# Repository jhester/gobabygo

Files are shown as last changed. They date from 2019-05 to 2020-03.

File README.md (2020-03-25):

GoBabyGo Project Repository
=====

This repo holds the firmware, software, hardware, and other files fort the GoBabyGo utilization project.

#### Visualize Data with Google Earth

Use the `create_nmea.py` script in the `analysis` folder to convert gathered GPS data into a single [NMEA file](https://www.gpsworld.com/what-exactly-is-gps-nmea-data/) which can be dragged into [Google Earth Pro (free)](https://www.google.com/earth/versions/#earth-pro), the desktop app.

To do this you need Python, once installed run the following in a command prompt or in a terminal where you specify the path to all the data and then specify the name of the NMEA file:

```
python create_nmea.py folder/where/files/are -o outputfile.nmea
```

If you import only tracks, it renders faster  but you dont get each value. If you import the LineStrings then it shows every value and also shows direction and time which is nice.

This could be trimmed down to show per day possibly.

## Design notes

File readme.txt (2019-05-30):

How to use it?

1. install SW4STM32
2. open SW4STM32/STM32L47xx_SensorTile/.project

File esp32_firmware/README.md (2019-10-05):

ESP32 Thing Based GoBabyGo! Firmware
=====

After difficulty deploying and programming SensorTiles we opted to go with the higher power but more feature rich ESP32.

Specifically this breakout board [SparkFun ESP32 Thing](https://www.sparkfun.com/products/13907). Which has a chip that allows BLE and Wifi connections along with decent performance and ease of programming using Arduino. 

We deploy with the [SparkFun ESP32 Thing Motion Shield](https://www.sparkfun.com/products/14430) connected to a [GPS Receiver - GP-20U7 (56 Channel)](https://www.sparkfun.com/products/13740).

Thie allows us to get GPS coordinates, very accurate global time, and IMU data for tracking movement. This is all stored to the USB. GPS updates once per second. IMU updates 10 times a second. Tested and can get a GPS lock indoors and when moved around it can map the movement. 

#### Function
1. Blue led pulses while trying to find a lock, and is solid blue when lock found.
2. The sd card can be taken out without corrupting data, but if inserted again, need to click the reset button and it will pick up from where it left off.
3. files only grow to a set size, then a new file is created for data, in the format of IMU_00001.txt, GPS_00001.txt, IMU_00002.txt and so on
4. the files are synchronized by a local timer which is the first column in each file, so all data can be aligned.
5. the GPS gives exact time (basically the standard time that everything else is set by). So even if a power failure happens we can always get the right time just by asking GPS.

#### Resources
1. [NMEA reference for GPS data](https://www.sparkfun.com/datasheets/GPS/NMEA%20Reference%20Manual-Rev2.1-Dec07.pdf)
2. [Motion breakout guide.](https://learn.sparkfun.com/tutorials/esp32-thing-motion-shield-hookup-guide)

#### TODO and Ideas

**Data Upload:** Use the BLE and Wifi together to create an in-wild auto data upload mechanism. The process would be:
1. Read network.txt SD card for Wifi info and attempt to authenticate with it if it exists.
2. If this file does not exist, OR the network is unavailable. Then go into BLE mode and listen for a connection. Also go about normal data collection.
3. If a connection is made in BLE mode, talk over UART and ask for Wifi SSID and password. Then connect and store it once found.

**Even easier. Have the participants or study coordinator make a file on the SD card with the SSID and password for the network and then the ESP32 will just connect to it.**

esp 32 imag

---------

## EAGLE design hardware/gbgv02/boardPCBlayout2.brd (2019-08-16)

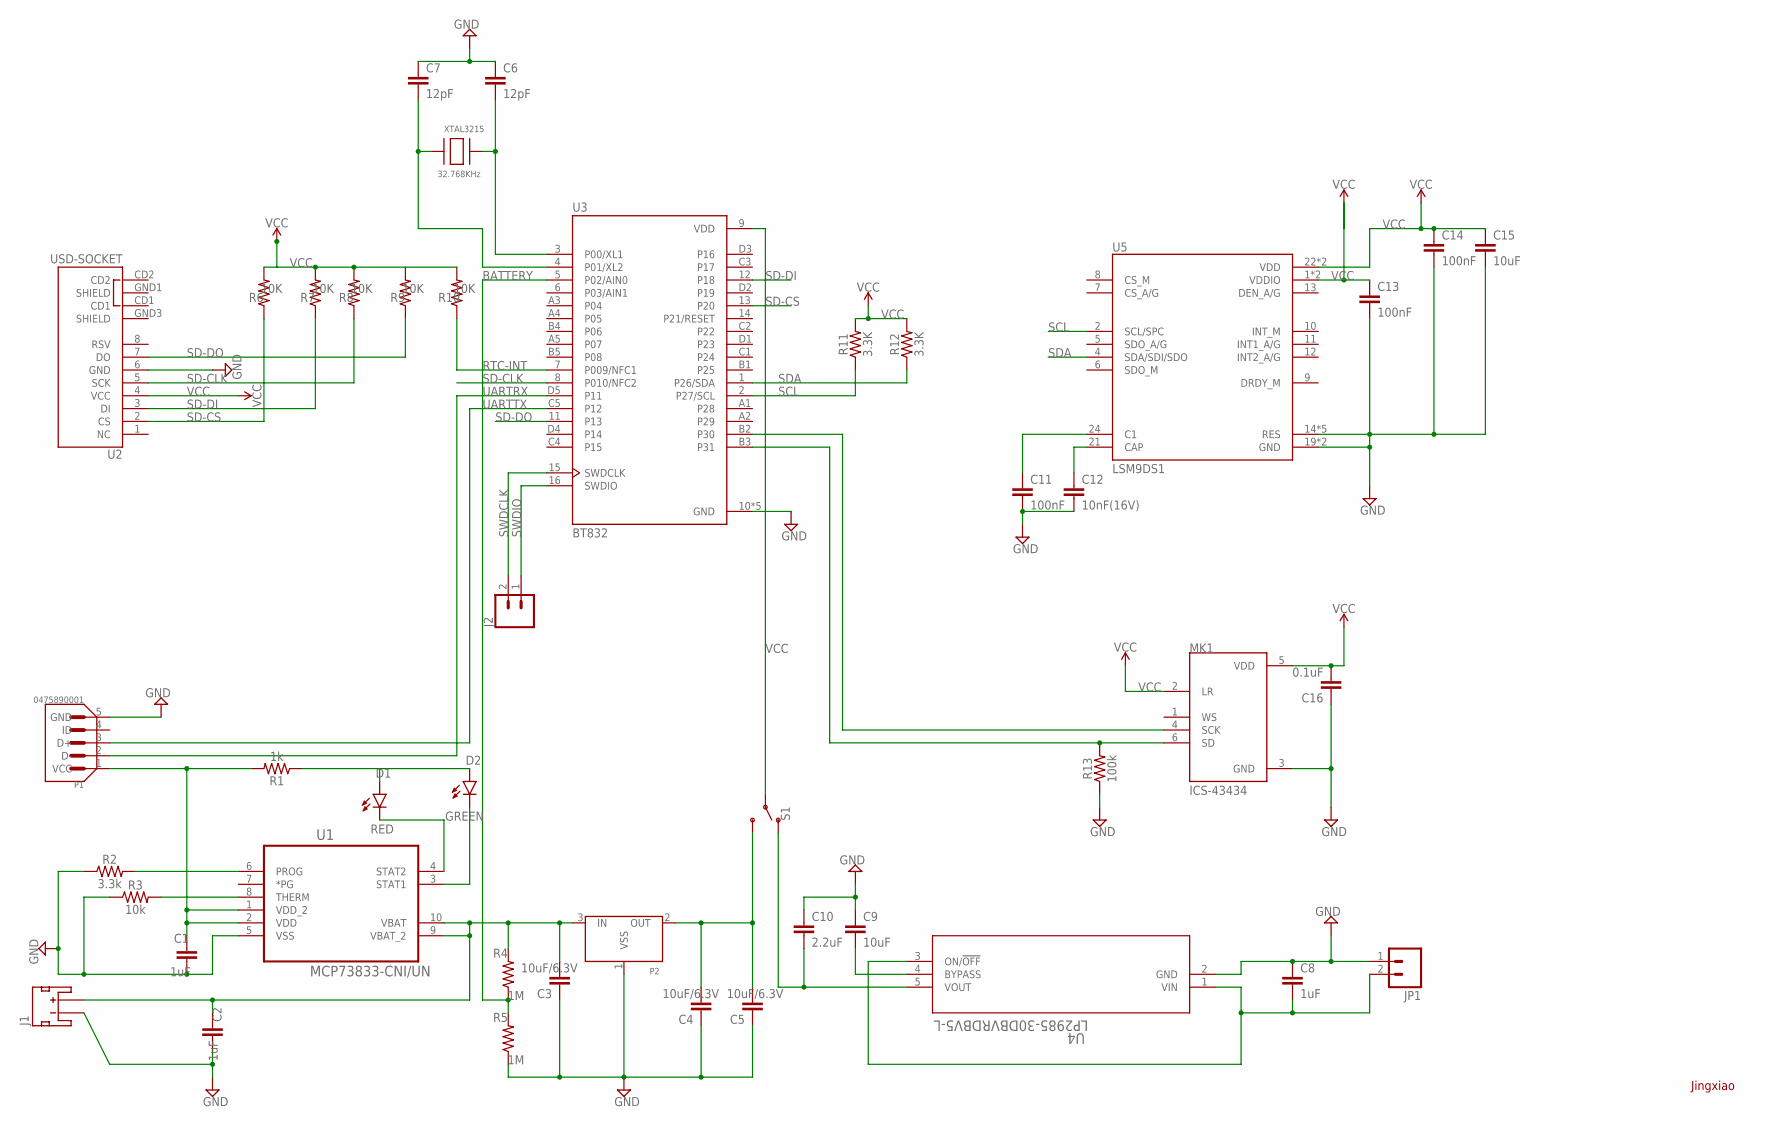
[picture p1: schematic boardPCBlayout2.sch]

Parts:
C1, C2: 1uF; CAP_0603
C3, C4, C5: 10uF/6.3V; 0603
C6, C7: 12pF; 0603
C8: 1uF; 0603
C9, C15: 10uF; 0603
C10: 2.2uF; 0603
C11, C13, C14: 100nF; 0603
C12: 10nF(16V); 0603
C16: 0.1uF; 0603
D1: RED; LED-0603
D2: GREEN; LED-0603
J1: JST_2MM_MALE; JST-2-SMD
J2: CONN_02; 1X02
JP1: M023.5MM-NO_SILK; SCREWTERMINAL-3.5MM-2-NS
MK1: ICS-43434; MIC_ICS-43434
P1: 0475890001; MOLEX_0475890001
P2: XC6206SOT-23; XC6206_SOT-23
R1: 1k; 0603
R2: 3.3k; 0603
R3: 10k; 0603
R4, R5: 1M; 0603
R6, R7, R8, R9, R10: 10K; 0603
R11, R12: 3.3K; 0603
R13: 100k; 0603
S1: SWITCH-SPDT-PTH-11.6X4.0MM; SWITCH_SPDT_PTH_11.6X4.0MM
U1: MCP73833-CNI/UN; SOP50P490X110-10N
U2: USD-SOCKET; MICROSD_1:1
U3: BT832; BLEMODULE_BT832
U4: LP2985-30DBVRDBV5-L; DBV5-L
U5: LSM9DS1; PQFN24P43_350X300X102L35X23N
XTAL3215: 32.768KHz; XTAL3215

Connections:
BATTERY: R4.1, R5.2, U3.5 (P02/AIN0)
GND: C1.2, C3.1, C4.1, C5.1, C6.1, C7.1, C8.1, C9.1, C10.1, C11.2, C12.2, C13.2, C14.2, C15.2, C16.1, JP1.1, MK1.3 (GND), P1.5 (GND), P2.1 (VSS), R2.1, R3.1, R5.1, R13.1, U1.5 (VSS), U2.6 (GND), U3.10 (GND), U3.A0 (GND), U3.B0 (GND), U3.C0 (GND), U3.D0 (GND), U4.2 (GND), U5.14 (RES), U5.15 (RES), U5.16 (RES), U5.17 (RES), U5.18 (RES), U5.19 (GND), U5.20 (GND)
unnamed: C1.1, P1.1 (VCC), R1.2, U1.1 (VDD_2), U1.2 (VDD)
unnamed: D1.C, U1.4 (STAT2)
unnamed: D1.A, D2.A, R1.1
unnamed: D2.C, U1.3 (STAT1)
unnamed: C2.2, J1.1 (-)
unnamed: C2.1, C3.2, J1.2 (+), P2.3 (IN), R4.2, U1.9 (VBAT_2), U1.10 (VBAT)
unnamed: R2.2, U1.6 (PROG)
unnamed: R3.2, U1.8 (THERM)
unnamed: MK1.6 (SD), R13.2, U3.B3 (P31)
unnamed: C7.2, U3.4 (P01/XL2), XTAL3215.P$1
unnamed: C6.2, U3.3 (P00/XL1), XTAL3215.P$2
unnamed: C10.2, S1.1 (O), U4.5 (VOUT)
unnamed: C12.1, U5.21 (CAP)
unnamed: C8.2, JP1.2, U4.1 (VIN), U4.3 (ON/!OFF)
unnamed: C9.2, U4.4 (BYPASS)
unnamed: C11.1, U5.24 (C1)
unnamed: C4.2, C5.2, P2.2 (OUT), S1.3 (S)
unnamed: MK1.4 (SCK), U3.B2 (P30)
RTC-INT: R10.1, U3.7 (P009/NFC1)
SCL: R11.1, U3.2 (P27/SCL), U5.2 (SCL/SPC)
SD-CLK: R8.1, U2.5 (SCK), U3.8 (P010/NFC2)
SD-CS: R6.1, U2.2 (CS), U3.13 (P20)
SD-DI: R7.1, U2.3 (DI), U3.12 (P18)
SD-DO: R9.1, U2.7 (DO), U3.11 (P13)
SDA: R12.1, U3.1 (P26/SDA), U5.4 (SDA/SDI/SDO)
SWDCLK: J2.2, U3.15 (SWDCLK)
SWDIO: J2.1, U3.16 (SWDIO)
UARTRX: P1.2 (D-), U3.D5 (P11)
UARTTX: P1.3 (D+), U3.C5 (P12)
VCC: C13.1, C14.1, C15.1, C16.2, MK1.2 (LR), MK1.5 (VDD), R6.2, R7.2, R8.2, R9.2, R10.2, R11.2, R12.2, S1.2, U2.4 (VCC), U3.9 (VDD), U5.1 (VDDIO), U5.3 (VDDIO), U5.22 (VDD), U5.23 (VDD)

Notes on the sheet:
Jingxiao

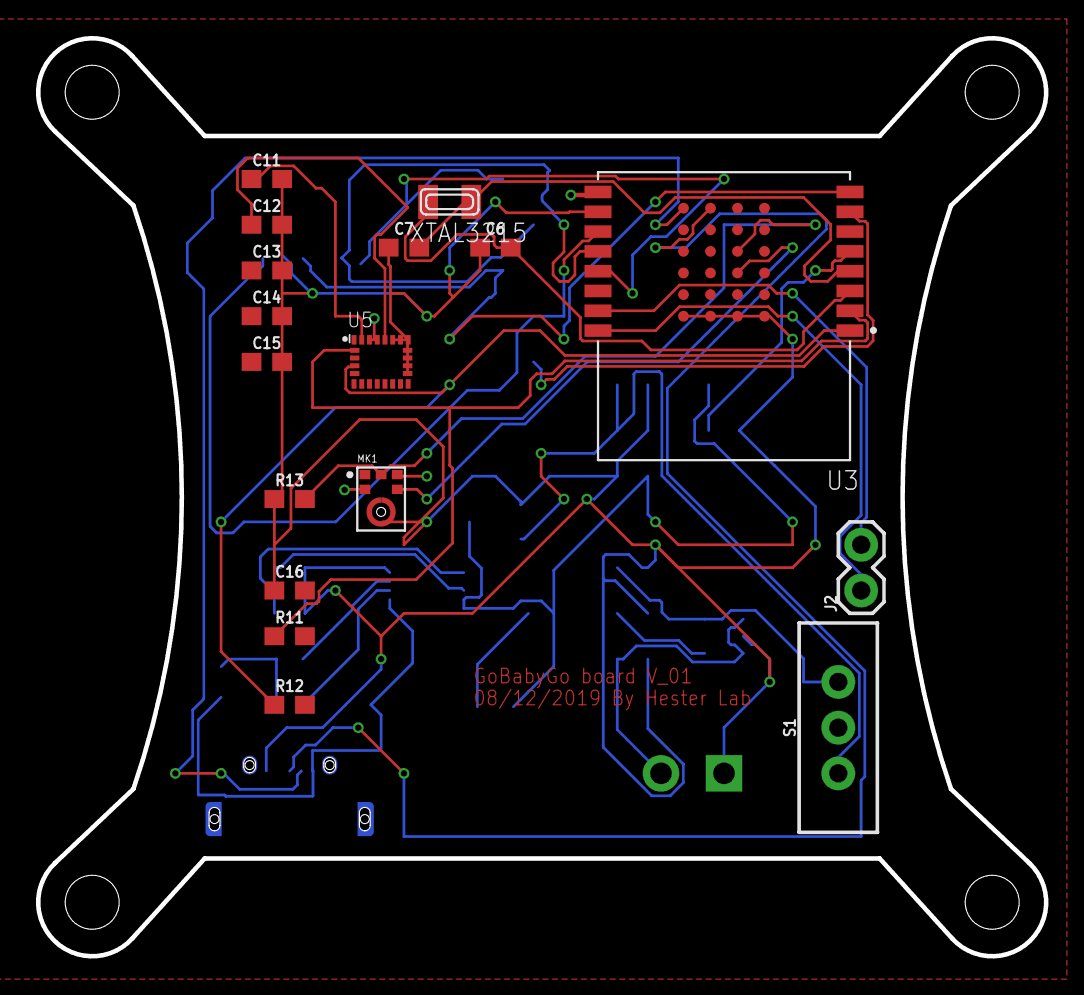
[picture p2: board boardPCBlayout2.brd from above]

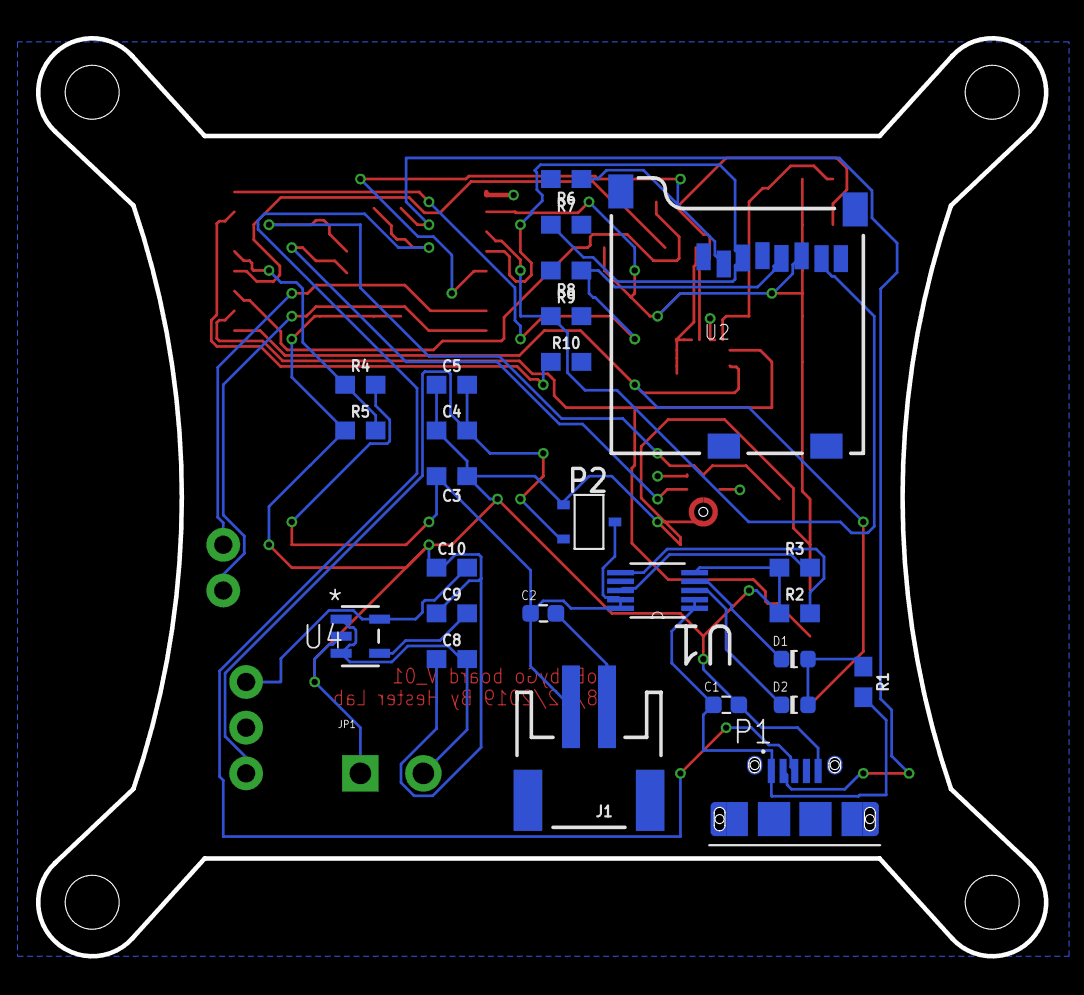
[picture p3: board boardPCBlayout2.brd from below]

Board: 2 copper layers, 56.0 x 51.0 mm, 44 parts (27 on the bottom side), 32 nets.

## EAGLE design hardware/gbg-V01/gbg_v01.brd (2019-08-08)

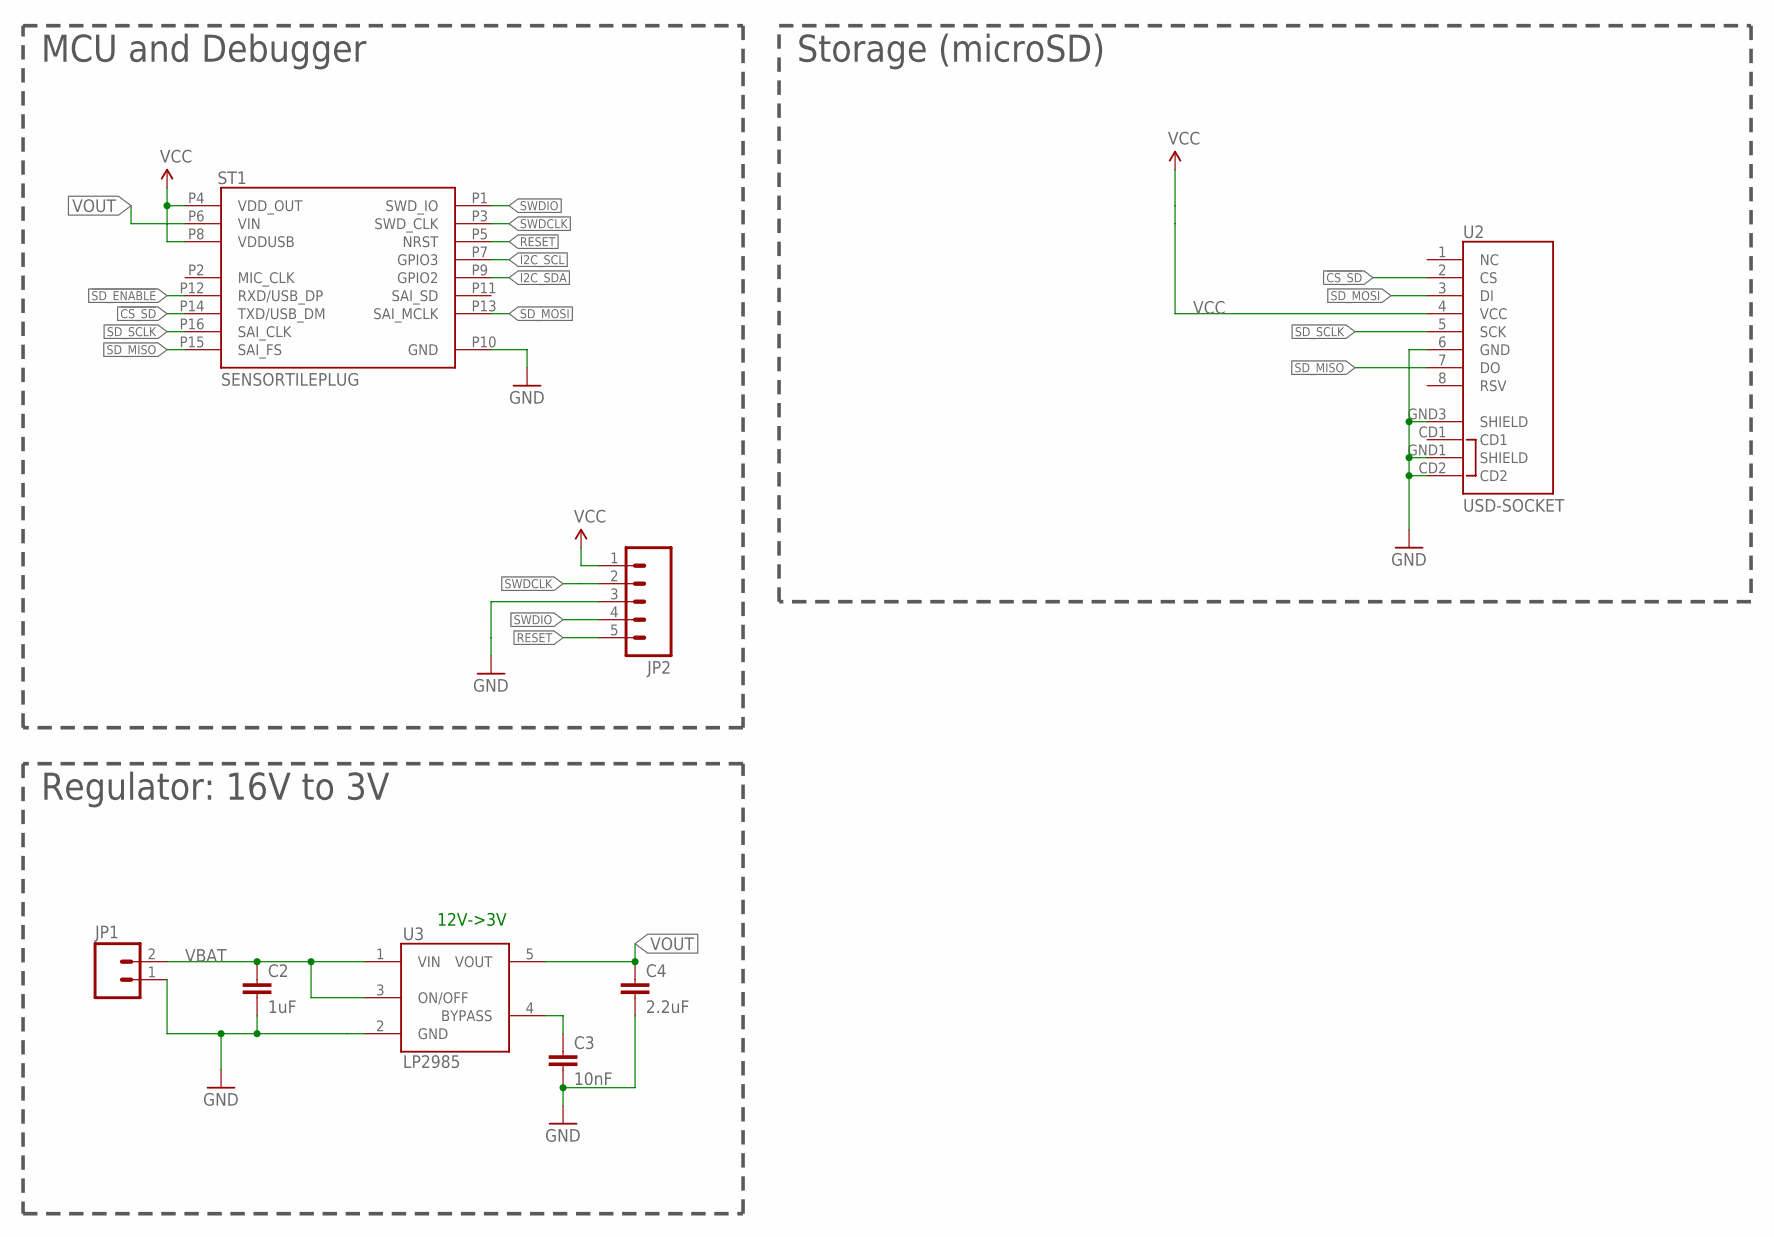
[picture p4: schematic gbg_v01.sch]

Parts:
C2: 1uF; 0603
C3: 10nF; 0603
C4: 2.2uF; 0603
JP1: M025MM; SCREWTERMINAL-5MM-2
JP2: M05LOCK; 1X05_LOCK
ST1: SENSORTILEPLUG; BM10JC16
U2: USD-SOCKET; MICROSD_1:1; DIGIKEY WM3290CT-ND
U3: LP2985AIM5-3.3; SOT25; MPN LP2985-30DBVR; DIGIKEY 296-32152-1-ND

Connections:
!CS_SD: ST1.P14 (TXD/USB_DM), U2.2 (CS)
!SD_ENABLE: ST1.P12 (RXD/USB_DP)
BYPASS: C3.1, U3.4 (BYPASS)
GND: C2.2, C3.2, C4.2, JP1.1, JP2.3, ST1.P10 (GND), U2.6 (GND), U2.CD2, U2.GND1 (SHIELD), U2.GND3 (SHIELD), U3.2 (GND)
I2C_SCL: ST1.P7 (GPIO3)
I2C_SDA: ST1.P9 (GPIO2)
RESET: JP2.5, ST1.P5 (NRST)
SD_MISO: ST1.P15 (SAI_FS), U2.7 (DO)
SD_MOSI: ST1.P13 (SAI_MCLK), U2.3 (DI)
SD_SCLK: ST1.P16 (SAI_CLK), U2.5 (SCK)
SWDCLK: JP2.2, ST1.P3 (SWD_CLK)
SWDIO: JP2.4, ST1.P1 (SWD_IO)
VBAT: C2.1, JP1.2, U3.1 (VIN), U3.3 (ON/OFF)
VCC: JP2.1, ST1.P4 (VDD_OUT), ST1.P8 (VDDUSB), U2.4 (VCC)
VOUT: C4.1, ST1.P6 (VIN), U3.5 (VOUT)

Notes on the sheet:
Storage (microSD)
12V->3V
MCU and Debugger
Regulator: 16V to 3V

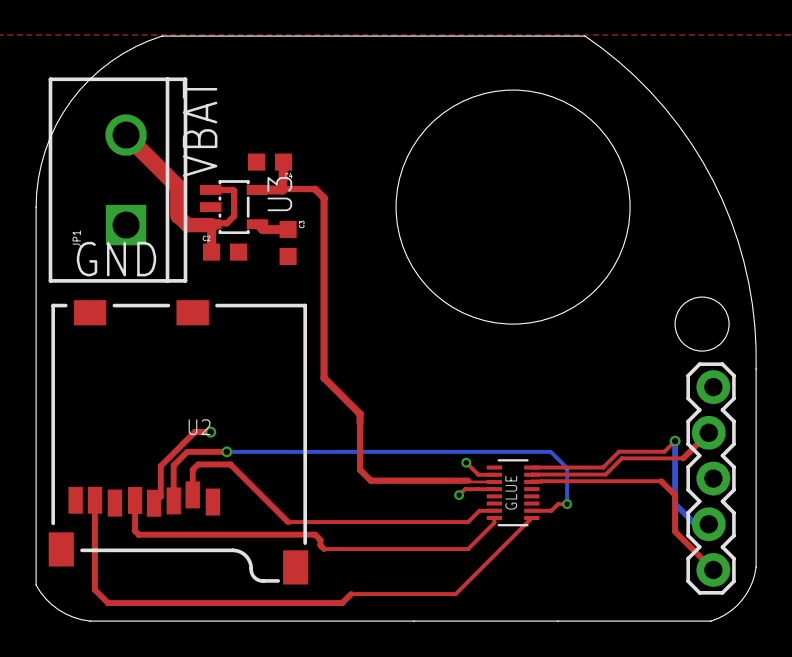
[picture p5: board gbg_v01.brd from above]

Board: 2 copper layers, 40.0 x 32.5 mm, 8 parts (0 on the bottom side), 12 nets.

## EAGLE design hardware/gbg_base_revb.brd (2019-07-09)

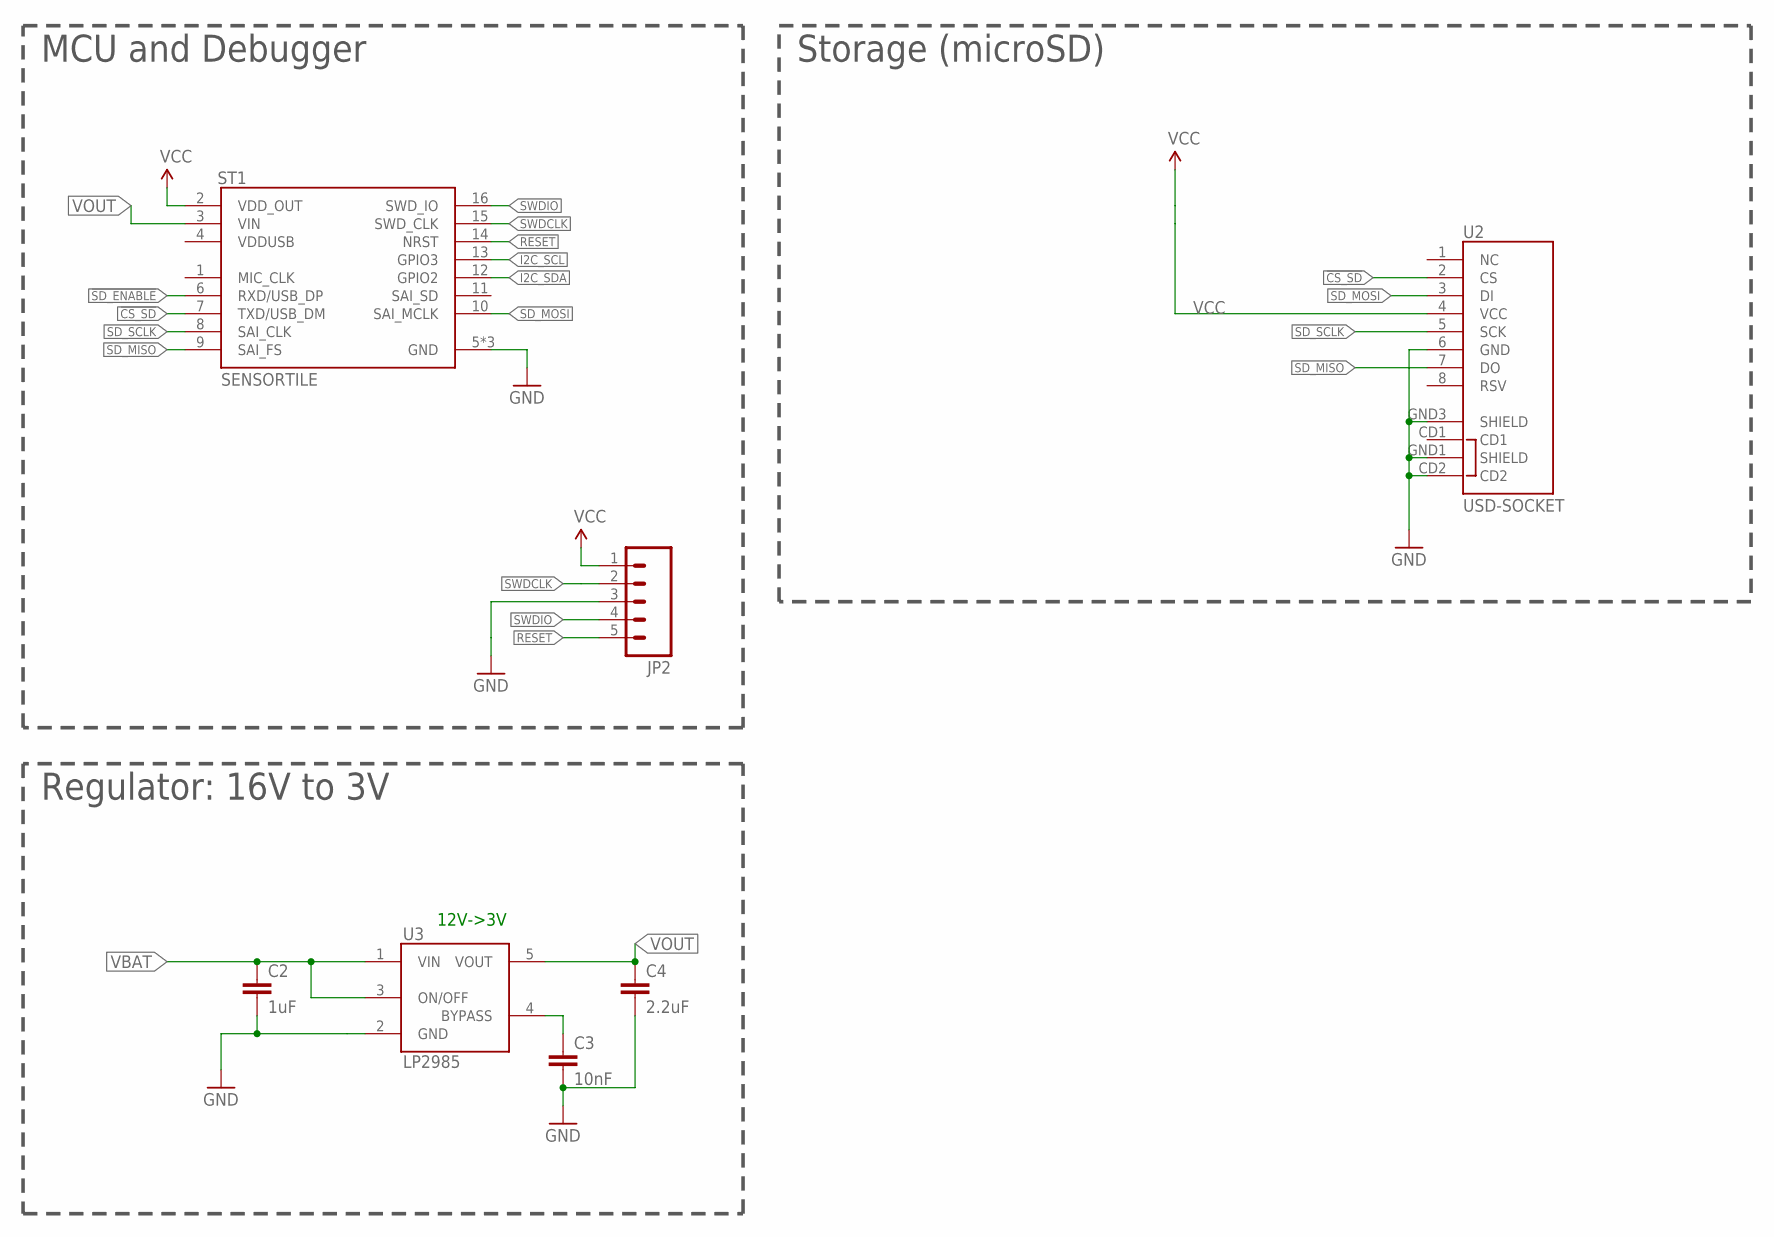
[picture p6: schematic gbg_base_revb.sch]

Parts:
C2: 1uF; 0603
C3: 10nF; 0603
C4: 2.2uF; 0603
JP2: M05LOCK; 1X05_LOCK
ST1: SENSORTILE
U2: USD-SOCKET; MICROSD_1:1; DIGIKEY WM3290CT-ND
U3: LP2985AIM5-3.3; SOT25; MPN LP2985-30DBVR; DIGIKEY 296-32152-1-ND

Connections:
!CS_SD: ST1.7 (TXD/USB_DM), U2.2 (CS)
!SD_ENABLE: ST1.6 (RXD/USB_DP)
BYPASS: C3.1, U3.4 (BYPASS)
GND: C2.2, C3.2, C4.2, JP2.3, ST1.5 (GND), ST1.17 (GND), ST1.18 (GND), U2.6 (GND), U2.CD2, U2.GND1 (SHIELD), U2.GND3 (SHIELD), U3.2 (GND)
I2C_SCL: ST1.13 (GPIO3)
I2C_SDA: ST1.12 (GPIO2)
RESET: JP2.5, ST1.14 (NRST)
SD_MISO: ST1.9 (SAI_FS), U2.7 (DO)
SD_MOSI: ST1.10 (SAI_MCLK), U2.3 (DI)
SD_SCLK: ST1.8 (SAI_CLK), U2.5 (SCK)
SWDCLK: JP2.2, ST1.15 (SWD_CLK)
SWDIO: JP2.4, ST1.16 (SWD_IO)
VBAT: C2.1, U3.1 (VIN), U3.3 (ON/OFF)
VCC: JP2.1, ST1.2 (VDD_OUT), U2.4 (VCC)
VOUT: C4.1, ST1.3 (VIN), U3.5 (VOUT)

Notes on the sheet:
Storage (microSD)
12V->3V
MCU and Debugger
Regulator: 16V to 3V

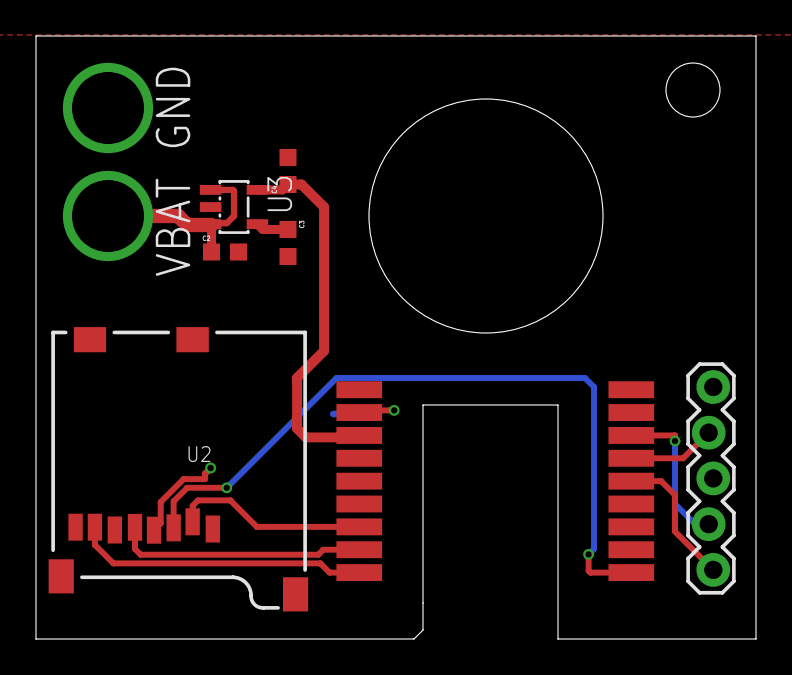
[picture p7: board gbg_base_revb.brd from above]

Board: 2 copper layers, 40.0 x 33.5 mm, 7 parts (0 on the bottom side), 12 nets.

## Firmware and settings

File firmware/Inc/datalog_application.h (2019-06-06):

/**
  ******************************************************************************
  * @file    datalog_application.h
  * @author  SRA - Central Labs
  * @version V2.0.0
  * @date    5-Feb-2019
  * @brief   Header for datalog_application.c module.
  ******************************************************************************
  * @attention
  *
  * <h2><center>&copy; COPYRIGHT(c) 2014 STMicroelectronics</center></h2>
  *
  * Licensed under MCD-ST Liberty SW License Agreement V2, (the "License");
  * You may not use this file except in compliance with the License.
  * You may obtain a copy of the License at:
  *
  *        http://www.st.com/software_license_agreement_liberty_v2
  *
  * Unless required by applicable law or agreed to in writing, software
  * distributed under the License is distributed on an "AS IS" BASIS,
  * WITHOUT WARRANTIES OR CONDITIONS OF ANY KIND, either express or implied.
  * See the License for the specific language governing permissions and
  * limitations under the License.
  *
  ******************************************************************************
  */

/* Define to prevent recursive inclusion -------------------------------------*/
#ifndef __DATALOG_APPLICATION_H
#define __DATALOG_APPLICATION_H

#ifdef __cplusplus
extern "C" {
#endif

#include "cube_hal.h"
#include "lsm6dsm_settings.h"
#include "lsm303agr_settings.h"
#include "SensorTile_env_sensors.h"
#include "hts221_settings.h"
#include "lps22hb_settings.h"
#include "SensorTile_motion_sensors.h"
#include "SensorTile_motion_sensors_ex.h"
  
#define SAMPLING_10Hz
//#define SAMPLING_50Hz
//#define SAMPLING_100Hz 

#if defined( SAMPLING_10Hz)
  #define DEFAULT_uhCCR1_Val 190
  #define ACCELERO_ODR 83.3f     /* after filtering will be 46.2 Hz */
  #define ACCELERO_DIV LSM6DSM_ACC_GYRO_HPCF_XL_DIV9
  #define GYRO_ODR 10.4f
  #define MAGNETO_ODR 10.0f
  #define PRESSURE_ODR 10.0f
  #define DATA_PERIOD_MS     (100)

#elif defined( SAMPLING_50Hz)
  #define DEFAULT_uhCCR1_Val 190
  #define ACCELERO_ODR 416.0f     /* after filtering will be 46.2 Hz */
  #define ACCELERO_DIV LSM6DSM_ACC_GYRO_HPCF_XL_DIV9
  #define GYRO_ODR 52.0f
  #define MAGNETO_ODR 50.0f
  #define PRESSURE_ODR 50.0f
  #define DATA_PERIOD_MS     (20)

#elif defined( SAMPLING_100Hz)
  #define DEFAULT_uhCCR1_Val 100
  #define ACCELERO_ODR  833.0f    /* after filtering will be 93 Hz */
  #define ACCELERO_DIV LSM6DSM_ACC_GYRO_HPCF_XL_DIV9
  #define GYRO_ODR 104.0f
  #define MAGNETO_ODR 100.0f
  #define PRESSURE_ODR 50.0f
  #define DATA_PERIOD_MS     (10)
#endif

#define TEMPERATURE_ODR 12.5f
#define HUMIDITY_ODR 12.5f

typedef enum
{
  USB_Datalog = 0,
  SDCARD_Datalog
} LogInterface_TypeDef;


typedef struct
{
  uint32_t ms_counter;
  float pressure;
  float humidity;
  float temperature;
  BSP_MOTION_SENSOR_Axes_t acc;
  BSP_MOTION_SENSOR_Axes_t gyro;
  BSP_MOTION_SENSOR_Axes_t mag;
} T_SensorsData;
  
extern LogInterface_TypeDef LoggingInterface;
extern volatile uint8_t SD_Log_Enabled;

void floatToInt( float in, int32_t *out_int, int32_t *out_dec, int32_t dec_prec );

void DATALOG_SD_Init(void);
uint8_t DATALOG_SD_Log_Enable(void);
uint8_t DATALOG_SD_writeBuf(char *s, uint32_t size);
void DATALOG_SD_Log_Disable(void);
void DATALOG_SD_DeInit(void);
void DATALOG_SD_NewLine(void);
int32_t getSensorsData( T_SensorsData *mptr);

void MX_X_CUBE_MEMS1_Init(void);
int32_t DoubleTap(void);

#ifdef __cplusplus
}
#endif

#endif /* __DATALOG_APPLICATION_H */

/************************ (C) COPYRIGHT STMicroelectronics *****END OF FILE****/

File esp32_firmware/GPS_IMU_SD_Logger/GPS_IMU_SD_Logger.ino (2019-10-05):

/*****************************************************************
GPS_IMU_SD_Logger.ino
Collect IMU and GPS data, log to SD

Marshall Taylor @ SparkFun Electronics
original creation date: Nov 6, 2017
https://github.com/sparkfun/ESP32_Motion_Shield

This example gathers IMU and GPS data and logs it to the card.

Hardware:
 *ESP32 Thing
 *ESP32 Motion Shield
 *micro SD card inserted
 *GP-20U7 in JST or GP-735 hand-wired

LEDS:

 *GPIO 5 (Onboard thing): Illuminates at start, turns off if:
   *Card not inserted
   *Mount failed
   *IMU start failed
   *File writing error
 *GPIO 13 (Onboard Motion Shield):
   *Blinks on RX GPS packet without lock
   *Solid on good GPS data

Resources:
  FileSerial.h
  FileSerial.cpp

Development environment specifics:
  IDE: Arduino 1.8.2
  ESP32 Arduino core

This code is beerware. If you see me (or any other SparkFun 
employee) at the local, and you've found our code helpful, 
please buy us a round!

Distributed as-is; no warranty is given.
*****************************************************************/
#include <Arduino.h>
#include "FileSerial.h"
#include <SparkFunLSM9DS1.h>

#define AUX_LED_PIN 13
#define ESP_LED_PIN 5

//HardwareSerial Serial1(2);  // UART1/Serial1 pins 16,17

FileSerial GPSLogFile(&Serial);
FileSerial IMULogFile(&Serial);

LSM9DS1 imu;  // Create an LSM9DS1 object

#define LSM9DS1_M	0x1E // Would be 0x1C if SDO_M is LOW
#define LSM9DS1_AG	0x6B // Would be 0x6A if SDO_AG is LOW

#define PRINT_SPEED 100 // 250 ms between prints
static unsigned long lastPrint = 0; // Keep track of print time

// Earth's magnetic field varies by location. Add or subtract 
// a declination to get a more accurate heading. Calculate 
// your's here:
// http://www.ngdc.noaa.gov/geomag-web/#declination
//#define DECLINATION -8.58 // Declination (degrees) in Boulder, CO.
#define DECLINATION 3.56 // Declination (degrees) in Chicago, IL

//Internal variables
float roll;
float pitch;
float heading;
char csvBuffer[300];


void setup(){
	pinMode(AUX_LED_PIN, OUTPUT);
	digitalWrite(AUX_LED_PIN, 0);
	
	pinMode(ESP_LED_PIN, OUTPUT);
	digitalWrite(ESP_LED_PIN, 1);
	
	delay(500);
	
    Serial.begin(115200);
	//Serial1.begin(9600);
  Serial1.begin(9600, SERIAL_8N1, 16, 17);
	
	//IMU
	// Configure LSM9DS1 library parameters
	imu.settings.device.commInterface = IMU_MODE_I2C;
	imu.settings.device.mAddress = LSM9DS1_M;
	imu.settings.device.agAddress = LSM9DS1_AG;
	imu.settings.mag.scale = 2;
	// The above lines will only take effect AFTER calling
	// imu.begin(), which verifies communication with the IMU
	// and turns it on.
	
	
	
	delay(1000);
	Serial.println("Starting Sketch");
	
	delay(100);
	if (!imu.begin())
	{
		Serial.println("Failed to communicate with LSM9DS1.");
		Serial.println("Double-check wiring.");
		Serial.println("Default settings in this sketch will " \
						"work for an out of the box LSM9DS1 " \
						"Breakout, but may need to be modified " \
						"if the board jumpers are.");
		digitalWrite(ESP_LED_PIN, 0);
		
		while (1);
	}
  
    if(!SD.begin(33, SPI, 10000000, "/sd")){
        Serial.println("Card Mount Failed");
		digitalWrite(ESP_LED_PIN, 0);
		while (1);
        return;
    }
    uint8_t cardType = SD.cardType();
	
    if(cardType == CARD_NONE){
        Serial.println("No SD card attached");
		digitalWrite(ESP_LED_PIN, 0);
		while (1);
        return;
    }

    Serial.print("SD Card Type: ");
    if(cardType == CARD_MMC){
        Serial.println("MMC");
    } else if(cardType == CARD_SD){
        Serial.println("SDSC");
    } else if(cardType == CARD_SDHC){
        Serial.println("SDHC");
    } else {
        Serial.println("UNKNOWN");
    }

    uint64_t cardSize = SD.cardSize() / (1024 * 1024);
    Serial.printf("SD Card Size: %lluMB\n", cardSize);

	//call begin with device, CS pin, port, frequency, and mount point.
	if(GPSLogFile.begin(&SD, 33, SPI, 10000000, "/sd") == 0)
	{
		Serial.println("SD begin did not succeed, halting.");
		digitalWrite(ESP_LED_PIN, 0);
		while(1);
	}

	//call begin with device, CS pin, port, frequency, and mount point.
	if(IMULogFile.begin(&SD, 33, SPI, 10000000, "/sd") == 0)
	{
		Serial.println("SD begin did not succeed, halting.");
		digitalWrite(ESP_LED_PIN, 0);
		while(1);
	}	

	GPSLogFile.setMaxFileSize(100000);
	GPSLogFile.setWriteBufferSize(90);
	GPSLogFile.startLog("logFiles", "GPS_");

	IMULogFile.setMaxFileSize(100000);
	IMULogFile.setWriteBufferSize(90);
	IMULogFile.startLog("logFiles", "IMU_");

}

int parsingState = 0;
char parseBuffer[200];
int parseBufferPtr = 0;


void loop(){
	//Pass gps data to the SD card
	switch(parsingState)
	{
		case 0: //reset buffer
			parseBuffer[0] = '$';
			parseBufferPtr = 1;
			parsingState = 1;
		break;
		case 1:
			if(Serial1.available())
			{
				char c = Serial1.read();
				if(c == '$')
				{
					//detected end
					parseBuffer[parseBufferPtr] = 0;
					parseBufferPtr++;
					//Pick out good messsage
					if(( parseBuffer[1] == 'G')&&( parseBuffer[2] == 'P')&&( parseBuffer[3] == 'R')&&( parseBuffer[4] == 'M')&&( parseBuffer[5] == 'C'))
					{
						// millis as a sync time for the two sensors
						GPSLogFile.print(millis());
            GPSLogFile.print(",");
						GPSLogFile.print(parseBuffer);
						//Output data to terminal for debug
						//Serial.print(parseBuffer);
						//
						digitalWrite(AUX_LED_PIN, 1);
						delay(1);
						int seekPtr = 0;
						while((parseBuffer[seekPtr] != ',')&&(seekPtr < 25))
						{
							seekPtr++;
						}
						seekPtr++;
						while((parseBuffer[seekPtr] != ',')&&(seekPtr < 25))
						{
							seekPtr++;
						}
						seekPtr++;
						if(parseBuffer[seekPtr] == 'A')
						{
							//digitalWrite(AUX_LED_PIN, 1);
						}
						else
						{
							digitalWrite(AUX_LED_PIN, 0);
						}
						
					}
					parsingState = 0;
				}
				else
				{
					parseBuffer[parseBufferPtr] = c;
					parseBufferPtr++;
				}					
			}
		break;
		default:
		break;
	}
	if ((lastPrint + PRINT_SPEED) < millis())
	{
		if ( imu.gyroAvailable() ) imu.readGyro();
		if ( imu.accelAvailable() ) imu.readAccel();
		if ( imu.magAvailable() ) imu.readMag();
		// Print the heading and orientation for fun!
		// Call print attitude. The LSM9DS1's mag x and y
		// axes are opposite to the accelerometer, so my, mx are
		// substituted for each other.
		//calcAttitude(imu.ax, imu.ay, imu.az, -imu.my, -imu.mx, imu.mz);
    int timestamp = millis();
		float data1 = imu.calcGyro(imu.gx);
		float data2 = imu.calcGyro(imu.gy);
		float data3 = imu.calcGyro(imu.gz);
		float data4 = imu.calcAccel(imu.ax);
		float data5 = imu.calcAccel(imu.ay);
		float data6 = imu.calcAccel(imu.az);
		float data7 = imu.calcMag(imu.mx);
		float data8 = imu.calcMag(imu.my);
		float data9 = imu.calcMag(imu.mz);
		
		sprintf(csvBuffer, "%d, %4.3f,%4.3f,%4.3f,%4.3f,%4.3f,%4.3f,%4.3f,%4.3f,%4.3f,", timestamp, data1, data2, data3, data4, data5, data6, data7, data8, data9);//, roll, pitch, heading);
		//Output data to terminal for debug
		//Serial.print(csvBuffer);
		//Serial.println();
		//
		IMULogFile.println(csvBuffer);
//		IMULogFile.print(0x0D);
//		IMULogFile.print(0x0A);
		
		lastPrint = millis(); // Update lastPrint time
	}
}

void calcAttitude(float ax, float ay, float az, float mx, float my, float mz)
{
	roll = atan2(ay, az);
	pitch = atan2(-ax, sqrt(ay * ay + az * az));
	heading;
	
	if (my == 0)
		heading = (mx < 0) ? PI : 0;
	else
		heading = atan2(mx, my);
	
	heading -= DECLINATION * PI / 180;
	
	if (heading > PI) heading -= (2 * PI);
	else if (heading < -PI) heading += (2 * PI);
	else if (heading < 0) heading += 2 * PI;
	
	// Convert everything from radians to degrees:
	heading *= 180.0 / PI;
	pitch *= 180.0 / PI;
	roll  *= 180.0 / PI;
}

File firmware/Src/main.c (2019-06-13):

/**
  ******************************************************************************
  * @file    main.c
  * @author  SRA - Central Labs
  * @version V2.0.0
  * @date    5-Feb-2019
  * @brief   Main program body
  ******************************************************************************
  * @attention
  *
  * <h2><center>&copy; Copyright (c) 2016 STMicroelectronics International N.V. 
  * All rights reserved.</center></h2>
  *
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
  ******************************************************************************
  */

/* Includes ------------------------------------------------------------------*/
#include "main.h"
#include "cmsis_os.h"
#include "datalog_application.h"
    
/* Private typedef -----------------------------------------------------------*/
/* Private define ------------------------------------------------------------*/

#define DATAQUEUE_SIZE     ((uint32_t)100)

#define DATALOG_CMD_STARTSTOP  (0x00000007)
    
typedef enum
{
  THREAD_1 = 0,
  THREAD_2
} Thread_TypeDef;
  
/* Private variables ---------------------------------------------------------*/

osThreadId GetDataThreadId, WriteDataThreadId;

osMessageQId dataQueue_id;
osMessageQDef(dataqueue, DATAQUEUE_SIZE, int);

osPoolId sensorPool_id;
osPoolDef(sensorPool, DATAQUEUE_SIZE, T_SensorsData);

osSemaphoreId readDataSem_id;
osSemaphoreDef(readDataSem);

/* LoggingInterface = USB_Datalog  --> Send sensors data via USB */
/* LoggingInterface = SDCARD_Datalog  --> Save sensors data on SDCard (enable with double click)Send sensors data via USB */
LogInterface_TypeDef LoggingInterface = SDCARD_Datalog;

USBD_HandleTypeDef  USBD_Device;
static volatile uint8_t MEMSInterrupt = 0;
volatile uint8_t no_H_HTS221 = 0;
volatile uint8_t no_T_HTS221 = 0;

/* Private function prototypes -----------------------------------------------*/
static void GetData_Thread(void const *argument);
static void WriteData_Thread(void const *argument);

static void Error_Handler( void );
void dataTimer_Callback(void const *arg);
void dataTimerStart(void);
void dataTimerStop(void);

osTimerId sensorTimId;
osTimerDef(SensorTimer, dataTimer_Callback);

uint32_t  exec;

static int32_t LSM6DSM_Sensor_IO_ITConfig( void );
      
/* Private functions ---------------------------------------------------------*/

/**
  * @brief  Main program
  * @param  None
  * @retval None
  */
int main(void)
{
  HAL_Init();

  /* Configure the System clock to 80 MHz */
  SystemClock_Config();

  /* enable USB power on Pwrctrl CR2 register */
  HAL_PWREx_EnableVddUSB();
  HAL_PWREx_EnableVddIO2();

  /* Initialize LED */
//  BSP_LED_Init(LED1);
//  BSP_LED_Off(LED1);

  //SDcard mount
  DATALOG_SD_Init();


  //Enter sleep mode
//  __asm volatile( "wfi" );
//  HAL_PWR_EnterSLEEPMode(PWR_MAINREGULATOR_ON, PWR_SLEEPENTRY_WFI);

  /* Thread 1 definition */
  osThreadDef(THREAD_1, GetData_Thread, osPriorityAboveNormal, 0, configMINIMAL_STACK_SIZE*4);

  /* Thread 2 definition */
  osThreadDef(THREAD_2, WriteData_Thread, osPriorityNormal, 0, configMINIMAL_STACK_SIZE*4);

  /* Start thread 1 */
  GetDataThreadId = osThreadCreate(osThread(THREAD_1), NULL);

  /* Start thread 2 */
  WriteDataThreadId = osThreadCreate(osThread(THREAD_2), NULL);

  /* Start scheduler */
  osKernelStart();

  /* We should never get here as control is now taken by the scheduler */
  for(;;){
  }

}

/**
  * @brief  Get data raw from sensors to queue
  * @param  thread not used
  * @retval None
  */
static void GetData_Thread(void const *argument)
{
  (void) argument;
  T_SensorsData *mptr;
  
  sensorPool_id = osPoolCreate(osPool(sensorPool));
  dataQueue_id = osMessageCreate(osMessageQ(dataqueue), NULL);

  readDataSem_id = osSemaphoreCreate(osSemaphore(readDataSem), 1);
  osSemaphoreWait(readDataSem_id, osWaitForever);

  /* Initialize and Enable the available sensors */
  MX_X_CUBE_MEMS1_Init();

  /* COnfigure LSM6DSM Double Tap interrupt*/
//  LSM6DSM_Sensor_IO_ITConfig();

  for (;;)
  {
    osSemaphoreWait(readDataSem_id, osWaitForever);

      /* Try to allocate a memory block and check if is not NULL */
      mptr = osPoolAlloc(sensorPool_id);
      if(mptr != NULL)
      {
        if(getSensorsData(mptr) == BSP_ERROR_NONE)
        {
          /* Push the new memory Block in the Data Queue */
          if(osMessagePut(dataQueue_id, (uint32_t)mptr, osWaitForever) != osOK)
          {
            Error_Handler();
          }
        }
        else
        {
          Error_Handler();
        }
      }
      else
      {
        Error_Handler();
      }

  }
}


/**
  * @brief  Write data in the queue on file or streaming via USB
  * @param  argument not used
  * @retval None
  */
static void WriteData_Thread(void const *argument)
{
  (void) argument;
  osEvent evt;
  T_SensorsData *rptr;
  int size=0;
  char data_s[1000];//100 char each line * 10 line
  
  //initialize once
  while(SD_Log_Enabled != 1)
	{
	  if(DATALOG_SD_Log_Enable())
	  {
		SD_Log_Enabled=1;
		osDelay(100);
		dataTimerStart();
	  }
	  else
	  {
		//DATALOG_SD_Log_Disable();
		DATALOG_SD_DeInit();
		DATALOG_SD_Init();
		osDelay(100);
	  }
	}

  uint8_t messageCount=0;
  for (;;)
  {
    evt = osMessageGet(dataQueue_id, osWaitForever);  // wait for message
    if (evt.status == osEventMessage)
    {
        rptr = evt.value.p;

        size += sprintf(data_s+size, "%d, %d, %d, %d, %d, %d, %d, %d, %d, %d\r\n",
        		  		     (uint32_t) xTaskGetTickCount(),
        				     (int)rptr->acc.x, (int)rptr->acc.y, (int)rptr->acc.z,
        				     (int)rptr->gyro.x, (int)rptr->gyro.y, (int)rptr->gyro.z,
        				     (int)rptr->mag.x, (int)rptr->mag.y, (int)rptr->mag.z);
	    osPoolFree(sensorPool_id, rptr);      // free memory allocated for message
	    messageCount+=1;

	    if(messageCount==10){
	    	DATALOG_SD_writeBuf(data_s, size);
	    	messageCount=0;
	    	size=0;
	    }

    }
  }
}


void dataTimer_Callback(void const *arg)
{ 
  osSemaphoreRelease(readDataSem_id);
} 


void dataTimerStart(void)
{
  osStatus  status;
 
  // Create periodic timer
  exec = 1;
  sensorTimId = osTimerCreate(osTimer(SensorTimer), osTimerPeriodic, &exec);
  if (sensorTimId)  {
    status = osTimerStart (sensorTimId, DATA_PERIOD_MS);                // start timer
    if (status != osOK)  {
      // Timer could not be started
    } 
  }
}

void dataTimerStop(void)
{
  osTimerStop(sensorTimId);
}
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

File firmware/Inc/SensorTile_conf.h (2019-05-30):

/**
 ******************************************************************************
 * @file    SensorTile_conf.h
 * @author  SRA - Central Labs
 * @version V2.0.0
 * @date    5-Feb-2019
 * @brief   This file contains definitions for the MEMS components bus interfaces
 ******************************************************************************
 * @attention
 *
 * <h2><center>&copy; COPYRIGHT(c) 2018 STMicroelectronics</center></h2>
 *
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
 ******************************************************************************
 */

/* Define to prevent recursive inclusion -------------------------------------*/
#ifndef __SENSORTILE_CONF_H__
#define __SENSORTILE_CONF_H__

#ifdef __cplusplus
extern "C" {
#endif

/* Includes ------------------------------------------------------------------*/
#include "stm32l4xx_hal.h"
#include "SensorTile_bus.h"
#include "SensorTile_errno.h"
  
#define AUDIO_CHANNELS 				        1
#define AUDIO_SAMPLING_FREQUENCY 		        48000
#define BSP_AUDIO_IN_INSTANCE 1U   /* Define the audio peripheral used: 1U = DFSDM */  
#define BSP_AUDIO_OUT_INSTANCE 0U   /* Define the audio peripheral used: 0U = SAI */  

#define USE_MOTION_SENSOR_LSM6DSM_0        1U
#define USE_MOTION_SENSOR_LSM303AGR_ACC_0  0U
#define USE_MOTION_SENSOR_LSM303AGR_MAG_0  1U
#define USE_ENV_SENSOR_HTS221_0            1U
#define USE_ENV_SENSOR_LPS22HB_0           1U
  
#define BSP_LSM6DSM_INT2_GPIO_PORT           GPIOA
#define BSP_LSM6DSM_INT2_GPIO_CLK_ENABLE()   __GPIOA_CLK_ENABLE()
#define BSP_LSM6DSM_INT2_GPIO_CLK_DISABLE()  __GPIOA_CLK_DISABLE()
#define BSP_LSM6DSM_INT2                 GPIO_PIN_2
#define BSP_LSM6DSM_INT2_EXTI_IRQn           EXTI2_IRQn  

#define BSP_LSM6DSM_CS_PORT GPIOB
#define BSP_LSM6DSM_CS_PIN GPIO_PIN_12
#define BSP_LSM6DSM_CS_GPIO_CLK_ENABLE()  __GPIOB_CLK_ENABLE()

#define BSP_LSM303AGR_M_CS_PORT GPIOB
#define BSP_LSM303AGR_M_CS_PIN GPIO_PIN_1
#define BSP_LSM303AGR_M_CS_GPIO_CLK_ENABLE()  __GPIOB_CLK_ENABLE()
                                                
#define BSP_LSM303AGR_X_CS_PORT GPIOC
#define BSP_LSM303AGR_X_CS_PIN GPIO_PIN_4
#define BSP_LSM303AGR_X_CS_GPIO_CLK_ENABLE()  __GPIOC_CLK_ENABLE()

#define BSP_LPS22HB_CS_PORT GPIOA
#define BSP_LPS22HB_CS_PIN GPIO_PIN_3
#define BSP_LPS22HB_CS_GPIO_CLK_ENABLE()  __GPIOA_CLK_ENABLE()

#ifdef __cplusplus
}
#endif

#endif /* __SENSORTILE_CONF_H__*/

/************************ (C) COPYRIGHT STMicroelectronics *****END OF FILE****/

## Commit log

2019-05-30 fixed bug, LED blink not implement
    [STSW-STLKT01-DataLog Debug.cfg]
2019-06-06 sample in 10Hz, write every 10-14 rows
2019-07-07 Update structure, add hardware files
    [STSW-STLKT01-DataLog Debug.cfg, gbg_base_reva.brd, gbg_base_reva.sch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]
2019-07-09 new hardware, simple
    [gbg_base_revb.brd, gbg_base_revb.sch]
2019-07-25 Create CAD
2019-08-14 visualization, basic calculation on location and distance
    [SensorTile_Log_N0.csv, SensorTile_Log_N2.csv, SensorTile_Log_N4.csv]
2019-08-21 Utilize magneto for direction
    [SensorTile_Log_N0.csv]
2019-10-05 added new esp32 arduino firmware
2020-03-25 moved things around, added script for google earth viz
    [SensorTile_Log_N4.csv]

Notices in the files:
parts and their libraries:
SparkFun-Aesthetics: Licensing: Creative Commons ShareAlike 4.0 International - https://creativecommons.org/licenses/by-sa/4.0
